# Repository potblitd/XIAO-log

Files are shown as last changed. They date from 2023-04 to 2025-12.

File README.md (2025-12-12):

<p align="center">
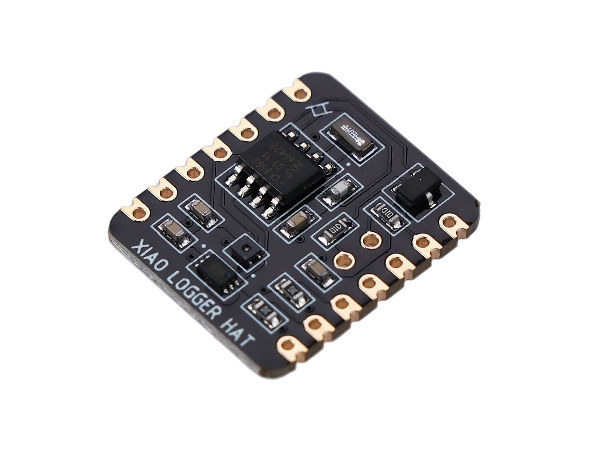
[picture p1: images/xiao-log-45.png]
  
  &nbsp;&nbsp;&nbsp;&nbsp;&nbsp;&nbsp;&nbsp;&nbsp;&nbsp;&nbsp;
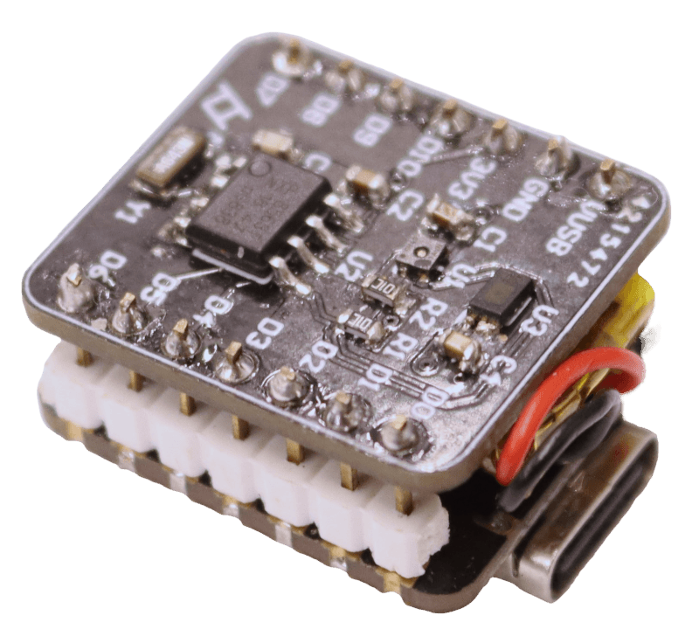
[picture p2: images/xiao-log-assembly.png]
  
</p>

An example _Arduino Zigbee_ code for the XIAO-log combined with a XIAO ESP32C6 micrcontroller can now be found [here](https://github.com/potblitd/XIAO-log/blob/main/zigbee/z-xiaohat.ino)

# XIAO log
The XIAO-LOG is a ‘hardware attached on top’ module for the XIAO Series microcontroller boards, providing temperature, humidity and ambient light measurements. The SHT40 and BH1750 sensors communicate through I2C, making it easy to program and get started. Their power supply is enabled by GPIO pin D10 to allow no-power sleep mode. Additionally, the onboard PCF8563 real-time clock can be used to keep precise timing and send a timed interrupt to the microcontroller. A voltage divider connected between the battery and the ADC output makes battery voltage monitoring possible. With its thumb-sized footprint and castellated header pins, this logger module perfectly fits on most of the XIAO boards and can accommodate more expansion boards. The module is a co-create collaboration with Seeed Studio and can be pruchased [here](https://www.seeedstudio.com/XIAO-LOG-p-6341.html).

## Description

The XIAO-LOG is a tiny environmental sensors module, specifically tailored for the XIAO microcontroller boards. It comprises two sensors : the SHT40 and the BH1750, measuring temperature, humidity, and ambient light. The chips use I2C communication on pin D4 and D5 to receive commands and send data to the XIAO microcontroller. On the same bus is also the PCF8563 real-time clock that provides precise timing and a programmable interrupt to wake up the XIAO board on pin D0 from deep sleep at exactly the right time. With these commonly used chips, the dev board can easily be programmed with existing libraries, both in micropython or on the arduino platform. 

For wireless battery-powered loggers, the resistor divider connecting the battery with ADC pin A3, is notably useful to monitor and keep track of the battery voltage level. To achieve the lowest power consumption, the sensors and the divider are powered through GPIO pin D10 while the always-on RTC chip only consumes about 250nA.

The dimensions of the XIAO-LOG board are the same as the XIAO boards, making it suitable for a sandwich configuration with the lithium-ion battery in between the two boards or for just stacking them. The castellated ‘post stamp’ headers on the board are friendly for breadboard setups and more HAT expansion layers.

## Specifications

| Item | Details |
| --- | --- |
| Size | 21mm x 17.75mm |
| Operating Temperature | -40°C to 85°C |
| Power Supply range | 2.4V ~ 3.6V |
| Current consumption | ~ 500uA |
| Idle current consumption | ~ 0.25uA |
| Communication Interface | I2C (D4/SDA and D5/SCL), ADC (D3/D3) |
| PCF8563 read time | TBA |
| SHT40 read time | ~ 2ms |
| BH1750 read time| ~ 120ms |
| Compatibility (all features) | XIAO ESP32C3, NRF54820, RP2350, MG24, ESP32C6 |
| Compatibility (no battery monitoring) | XIAO SAMD21, RP2040 | 

## Pinout Connections

## Programming

### Python
The easiest way to get micropython on the ESP32C3 chip is to download the firmware [here](https://micropython.org/download/), enter bootloader mode by holding the BOOT button down while pressing the RESET button, and then flash the chip with the bin file using [esptool](https://docs.espressif.com/projects/esptool/en/latest/esp32/) through the command prompt at the right COM port. With the [Thonny IDE](https://thonny.org/), the onboard files can easily be managed, and codes can be run directly without uploading them. 

This [basic code](code/xiaohat.py) implements all the features of the module.

Currently, the only way to connect the ESP32C3 board while in deep sleep for retrieving the log file, is to physically reset the board and click the restart backend button within the 10 seconds delay before the code continues and arrives back to deep sleep again. 

### Home Assistant 
The XIAO log devie can also be integrated into into Home Assistant thourgh ESPHome with this [example](code/esphome-xiaohat.yaml) code.

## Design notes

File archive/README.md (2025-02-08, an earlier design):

<p align="center">
  
</p>

# XIAO log

The lack of a simple and cost-effective device to measure temperature and humidity autonomously in remote, outdoor locations is astonishing. Specifically in ecological studies, to collect data, researchers often use the [Ibutton](https://www.ibuttonlink.com/collections/thermochron) logger that was released some 20 years ago and comes at a starting price of 36.70 USD. Needless to say, with today’s rise of CMOS, SoC, IoT and B2C, it’s about time to give those poor government-funded researchers an alternative and open-source solution for a simple temperature and humidity logging device. It should be noted that this post does not describe a buyable product but rather an easy setup with minimal components and cost.

## Materials

The XIAO log is composed of a microcontroller board, a battery and the temperature and humidity sensor probe. Although the [XIAO ESP32C3](https://www.seeedstudio.com/Seeed-XIAO-ESP32C3-p-5431.html) might seem a bit overkill for this application, it includes plenty of features that could be useful for future upgrades and variations. Also, its dirt [cheap](https://item.taobao.com/item.htm?spm=a230r.1.14.1.19487f1bpjLVY4&id=683550586572&ns=1&abbucket=17#detail) and trendy. For the sensor, a [waterproof probe](https://item.taobao.com/item.htm?spm=a230r.1.14.16.859f5271yamPh0&id=666936799925&ns=1&abbucket=17#detail) encasing the SHT40 chip (±0.2°C/±1.8%RH accuracy) should be suitable here. Lastly, the battery must be 3.7V lithium-ion to supply power and work with the dev board’s integrated battery charger. Its size can be chosen according to the housing dimensions. With [this waterproof box](https://detail.tmall.com/item.htm?id=681093549681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), the total cost of XIAO log is about 71.76 RMB or 10.45 USD.

<ins>Note</ins> : The XIAOs internal RTC is garbage. An external RTC should be used for reliable time keeping. See PCB shields [logRTC](#xiao-logrtc) or [log<sup>2</sup>](#log2).

<p align="center">
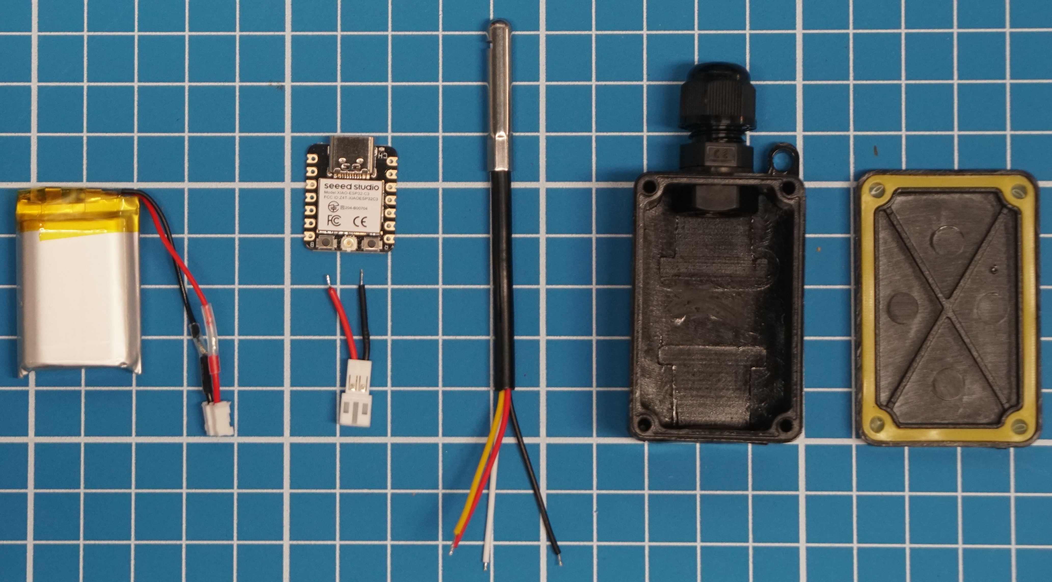
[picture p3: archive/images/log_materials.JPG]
  
</p>

## Assembly

Instead of soldering the battery directly onto the chip, a connector is fixed to facilitate removal and power OFF. The sensor uses I2C protocol which can be configured on pins D4 (SDA) and D5 (SCL). By connecting the VCC power supply for the sensor on a GPIO, such as D10, it can be powered only when needed and therefore reduce Xiao log's power consumption during his deep sleep period.

<p align="center">
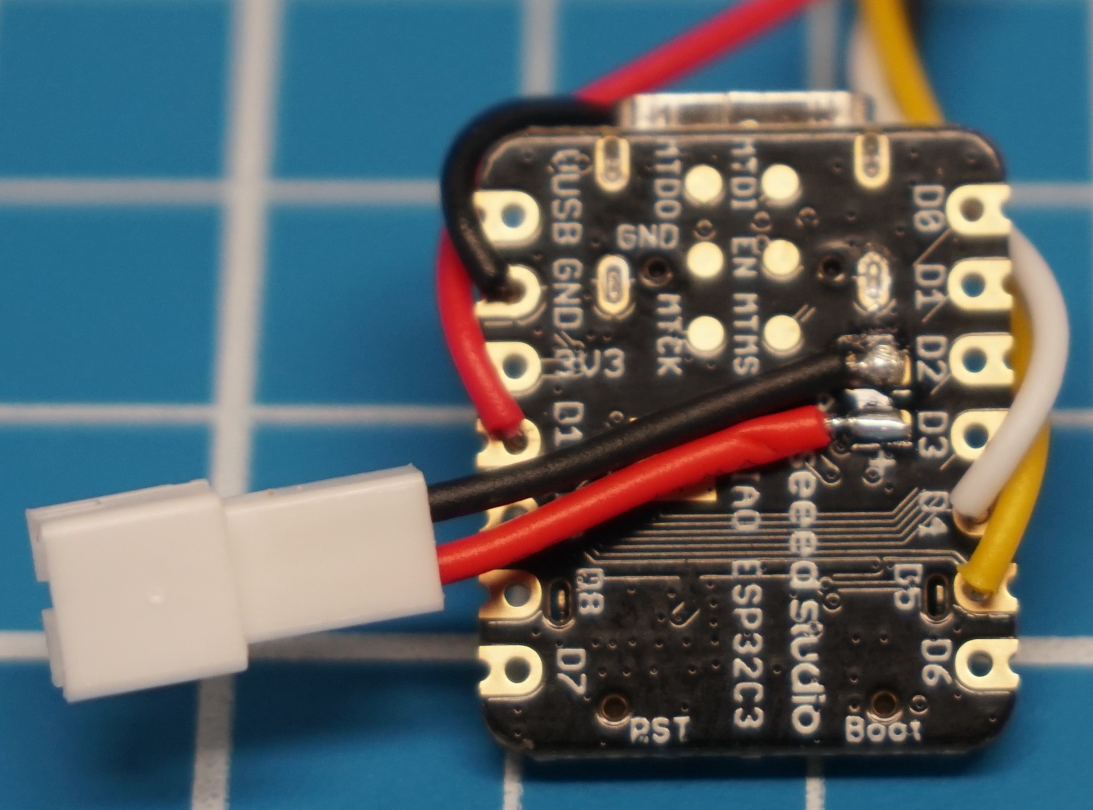
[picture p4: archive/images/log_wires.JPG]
  
  &nbsp;&nbsp;&nbsp;&nbsp;&nbsp;&nbsp;&nbsp;&nbsp;&nbsp;&nbsp;
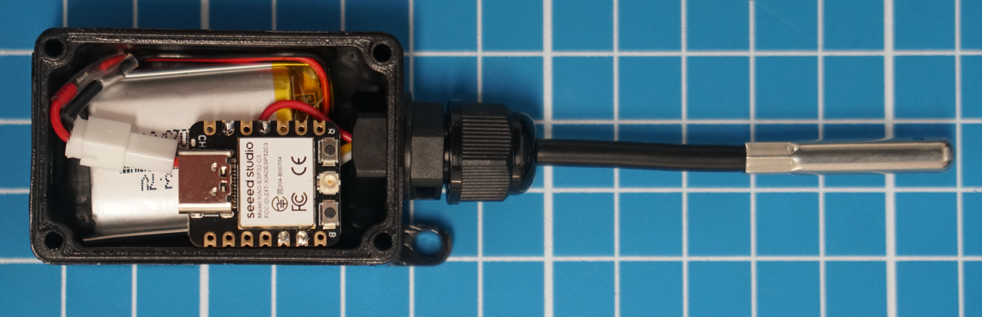
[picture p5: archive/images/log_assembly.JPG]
  
</p>

## Programming

The easiest way to get micropython on the ESP32C3 chip is to download the firmware [here](https://micropython.org/download/esp32c3-usb/), enter bootloader mode by holding the BOOT button down while pressing the RESET button, and then flash the chip with the bin file using [esptool](https://docs.espressif.com/projects/esptool/en/latest/esp32/) through the command prompt at the right COM port. With the [Thonny IDE](https://thonny.org/), the onboard files can easily be managed, and codes can be run directly without uploading them. The example code below is simple : it gets the RTC time, reads temperature and humidity from the sensor, writes all these values in a file and then calculates the time until the next measurement based on the logging period before going into deep sleep.

```ruby
# PARAMETERS
log_period = 60
 
# LIBRAIRIES
import os, time, machine

# DELAY ON RESET FOR IDE CONNECTION
if machine.reset_cause() == 1: time.sleep_ms(10000)
 
# DATE & TIME
now = time.localtime()
now_date = "-".join(map(str, now[0:3]))
now_time = ":".join(map(str, now[3:6]))
print("Date and time:", now_date, now_time)

# I2C INIT
i2c = machine.SoftI2C(sda=machine.Pin(6),scl=machine.Pin(7))

# TEMPERATURE & HUMIDITY
machine.Pin(10, machine.Pin.OUT).on()
time.sleep_ms(1)
i2c.writeto(0x44, bytes([0XFD]))
time.sleep_ms(10)
buf = i2c.readfrom(0x44, 6)
machine.Pin(10, machine.Pin.OUT).off()
temp = -45 + 175 * (buf[0]*256 + buf[1]) / 65535
humi = -6 + 125 * (buf[3]*256 + buf[4]) / 65535
print("Temperature: %0.2f C" % temp)
print("Humidity: %0.2f %%" % humi)
 
# VALUES LOG
if not "log.csv" in os.listdir():
    with open("log.csv", "a") as log:
        log.write("date,time,temp,hum\n")
with open("log.csv", "a") as log:
    log.write(now_date+","+now_time+","+str(temp)+","+str(humi)+"\n")
 
# DEEP SLEEP TIME
sleep_time = log_period - ((now[4]*60 + now[5]) % log_period)
print("Going to sleep for %0.2f minutes" % (sleep_time/60))
machine.deepsleep(sleep_time*1000)
# end
```

Currently, the only way to connect the ESP32C3 board while in deep sleep for retrieving the log file, is to physically reset the board and click the restart backend button within the 10 seconds delay before the code continues and arrives back to deep sleep again. 

## Performance

The current consumption during the measurements and logging is about 20mA and takes around 2 seconds. In deep sleep, XIAO log draws 42uA from his battery which is *nice* considering the RTC time is still running. So, with the 500mAh battery from this setup, XIAO log can theoretically run for 29 days with a 60 seconds logging cycle. The graph below shows his actual run with temperature, humidity and battery voltage measurement and file write every minute. After 35 days, the battery voltage dropped below 3.3V and the microcontroller stopped functioning which means the calculations above are reliable. With a log cycle of 10 minutes or 1 hour, XIAO log could therefore operate for 241 days or 392 days, respectively. 

<p align="center">
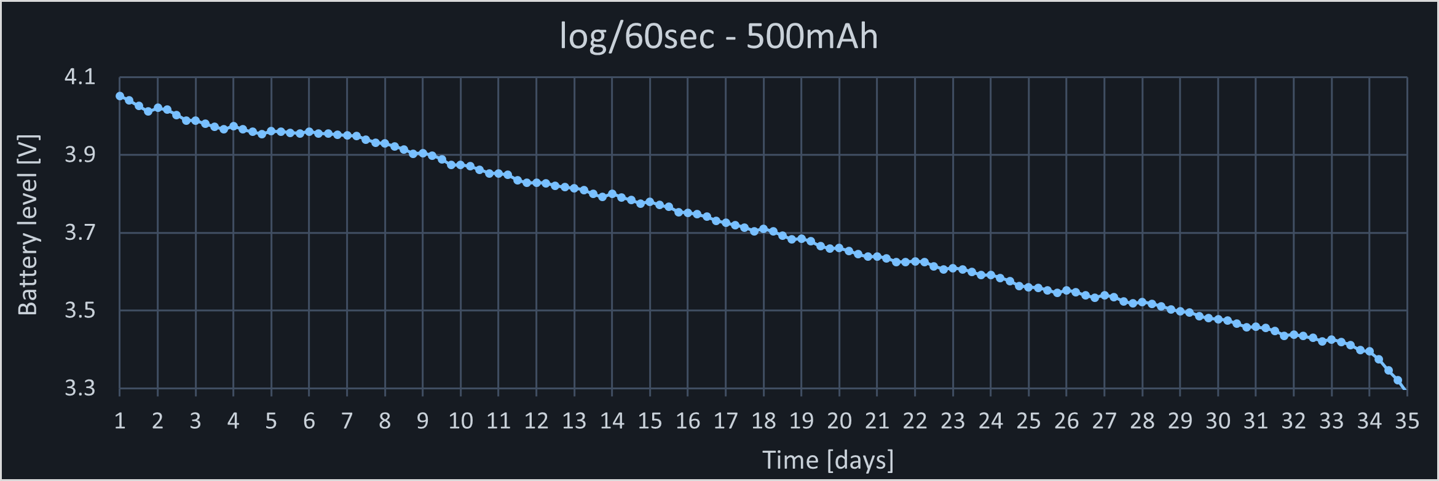
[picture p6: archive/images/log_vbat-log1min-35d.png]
  
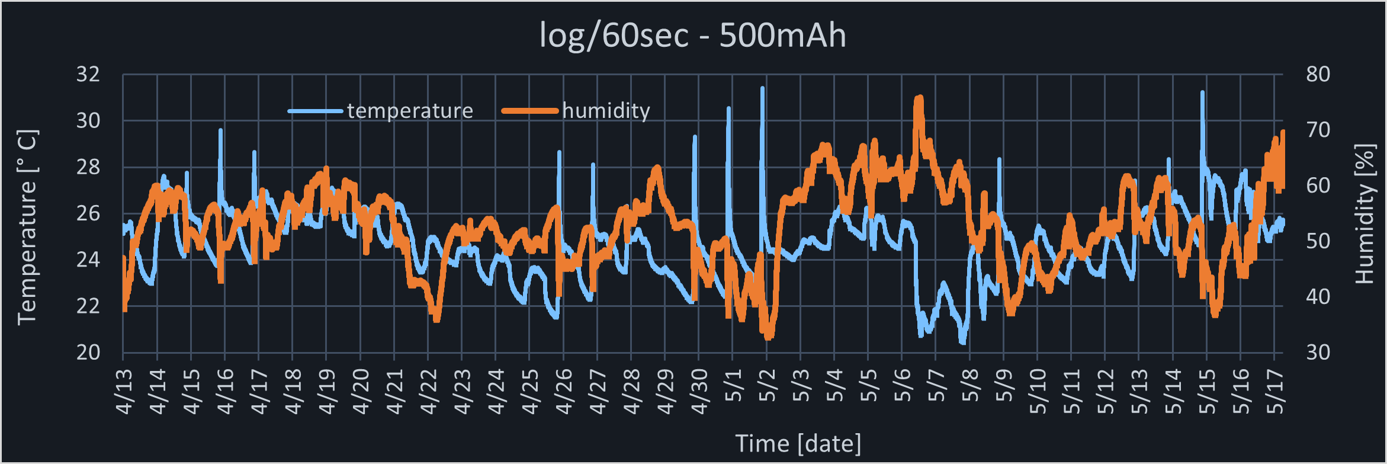
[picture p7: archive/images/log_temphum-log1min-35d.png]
  
</p>
It should also be noted that during this run, XIAO log didn't skip or mess up a single one of the total 49342 measurements and file logs. Good job XIAO log !

# [XIAO logRTC](logRTC)

Adding accurate time keeping and a battery voltage reading to the XIAO ESP32C3 with this weird shaped PCB. Here the PCF8563 RTC chip is powered continuously through the 3V3. The battery voltage divider is enabled through D10 and the halved voltage can be read on A3. Footprints and silkscreen are specifically designed to help for manual soldering.

<p align="center">
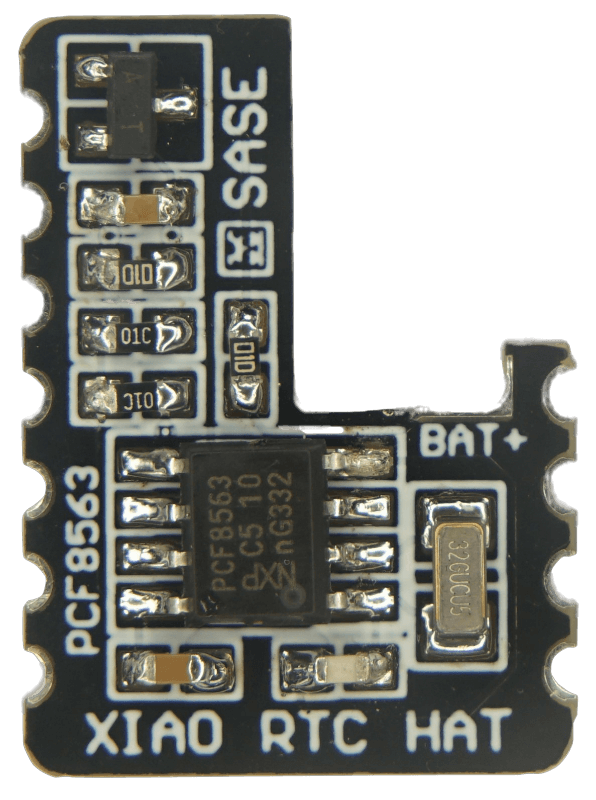
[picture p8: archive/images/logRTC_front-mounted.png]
  
  &nbsp;&nbsp;&nbsp;&nbsp;&nbsp;&nbsp;&nbsp;&nbsp;&nbsp;&nbsp;
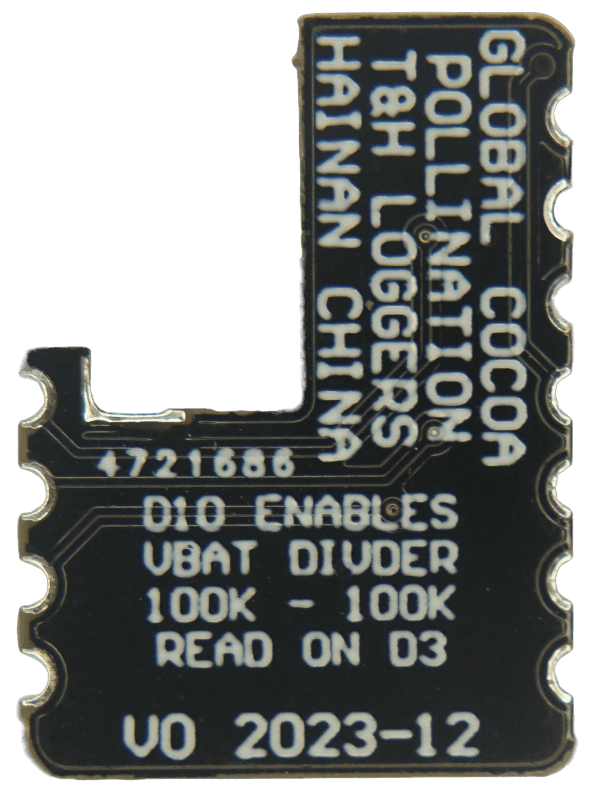
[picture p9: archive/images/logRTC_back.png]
  
</p>

## Assembly

After mounting the SMD components, the module is intended to be soldered directly onto the XIAO board (screw heat dissipation), connecting the BAT+ pins together while leaving space for a connector or wires. 

<p align="center">
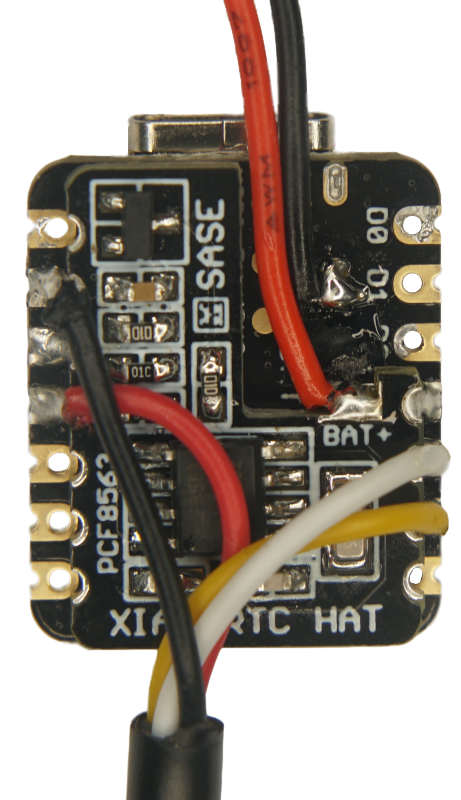
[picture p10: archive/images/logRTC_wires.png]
  
  &nbsp;&nbsp;&nbsp;&nbsp;&nbsp;&nbsp;&nbsp;&nbsp;&nbsp;&nbsp;
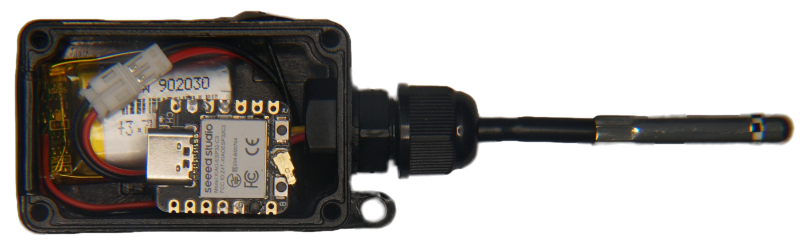
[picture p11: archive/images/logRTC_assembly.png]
  
</p>

## Code

[set_rtc.py](code/set_rtc.py) sets the time on PCF8563 form the local time on the PC.

The [xiaohat.py](code/xiaohat.py) code can be used for all variations in this repo. The *read_battery* parameter is used to enable battery voltage reading through D10 and A3. I2C comunication is initialized and, according to the adresses on the bus, values from the real-time clock (PCF8563), temperature & humidty sensor (SHT40) and ambient light sensor (BH1750) are retrieved. This data is then written into a file and send over WiFi to a cloud if *wifi_update* is enabled and its corresponding parameters are set up. Finally, the time until the next measurement is calculated based on the *log_period* time and deep sleep is activated.

Use the *test* variable to avoid the logger going to deep sleep and loosing connection when testing the code. Also, to access files when plugging the USB-C cable to a PC, resetting the board gives the user 10 seconds to connect to an IDE.

# [XIAO log<sup>2](log^2) <span id="log2"></span>

This design has 3 revisions. The latest one (V3) was adapted for the Seeed Studio Co-Create program.

Seeking compactness and all-in-one-ness, a logger hat hat was designed for the XIAO board. The design includes the previously used SHT40 temperature sensor, the popular BH1750 ambient light sensor and the PCF8563 RTC chip to correct the godawful internal clock. The RTC is powered by the 3V3 and the two sensor chips are powered through pin D10. Communication is done through I2C pins D4 (SDA) and D5 (SCL). V2 and V3 also features a battery voltage divider that is enabled through D10 and the halved voltage can be read on pin A3. This circuitry requires wiring the battery power to a through-hole pad on the hat. The PCB and components costs for this module sum up to 9.81 RMB (1.37 USD).

<p align="center">
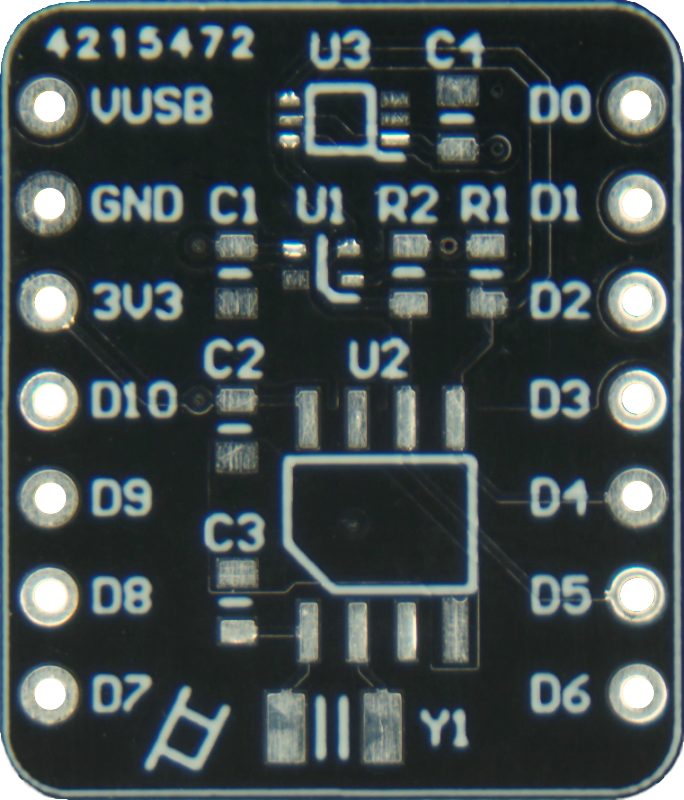
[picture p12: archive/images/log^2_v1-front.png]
  
  &nbsp;&nbsp;&nbsp;&nbsp;&nbsp;&nbsp;&nbsp;&nbsp;&nbsp;&nbsp;
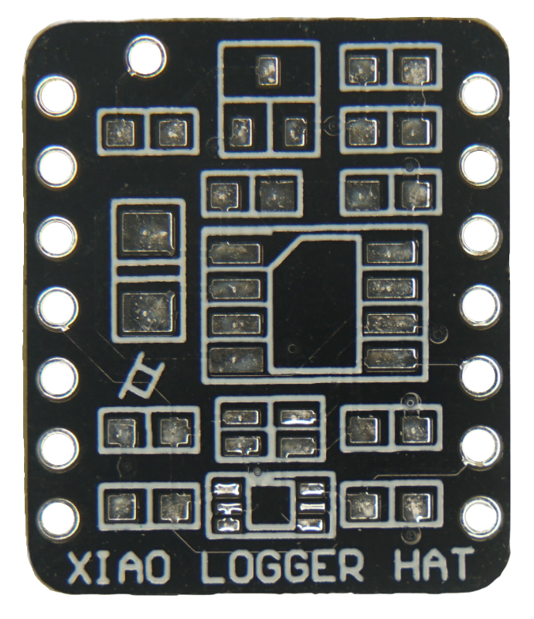
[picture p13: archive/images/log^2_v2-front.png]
  
  &nbsp;&nbsp;&nbsp;&nbsp;&nbsp;&nbsp;&nbsp;&nbsp;&nbsp;&nbsp;
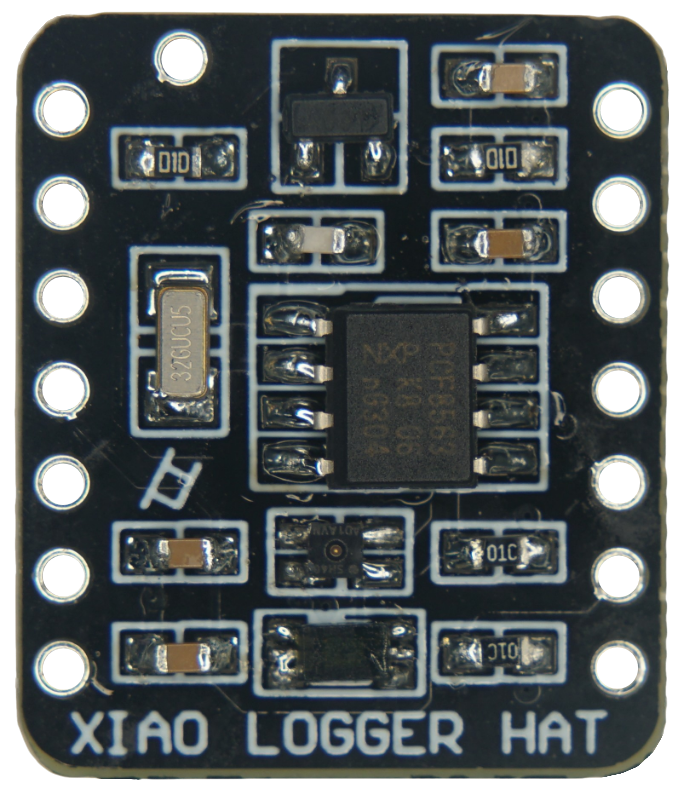
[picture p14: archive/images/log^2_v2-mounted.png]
  
</p>

## Assembly
SMD components are soldered on the shield first. V2 and V3 has adapted silkscreen and pads for easier manual soldering. The populated PCB is then soldered on the header pins of XIAO with an adequately-sized lithium battery sandwiched between the two boards. For V2 and V3, a wire must be added to get the battery voltage.

<p align="center">
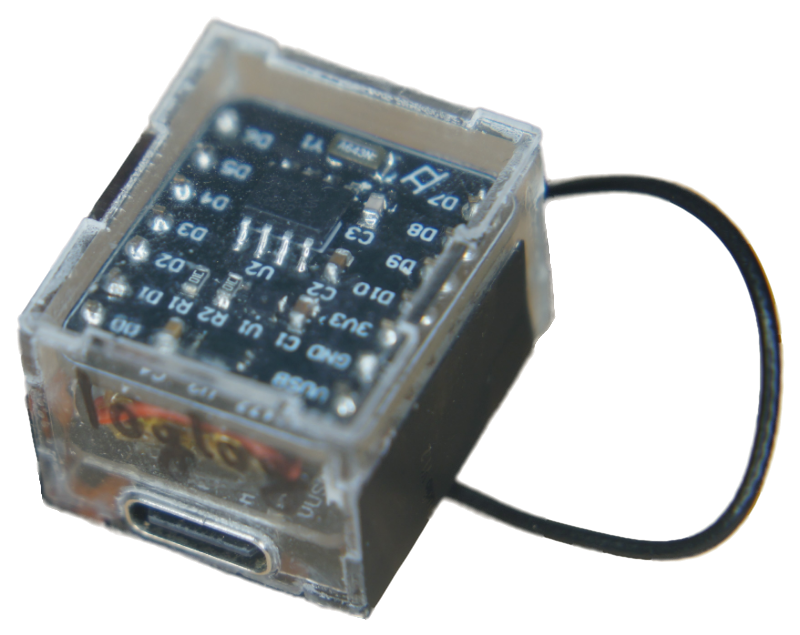
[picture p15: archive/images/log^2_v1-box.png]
  
  &nbsp;&nbsp;&nbsp;&nbsp;&nbsp;&nbsp;&nbsp;&nbsp;&nbsp;&nbsp;
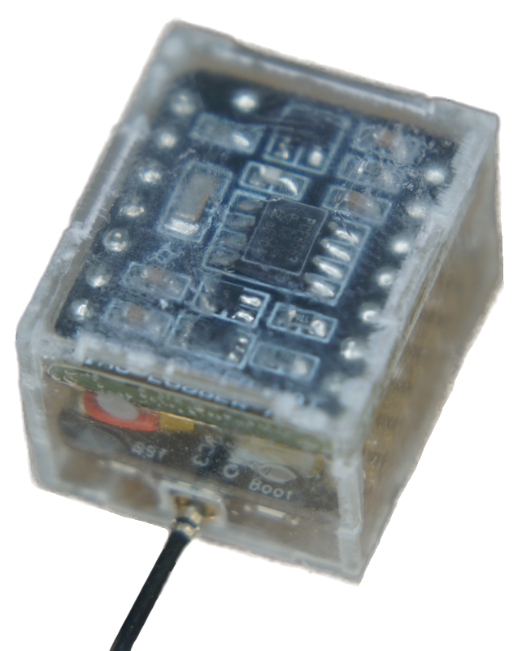
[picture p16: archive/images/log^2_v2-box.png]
  
  &nbsp;&nbsp;&nbsp;&nbsp;&nbsp;&nbsp;&nbsp;&nbsp;&nbsp;&nbsp;
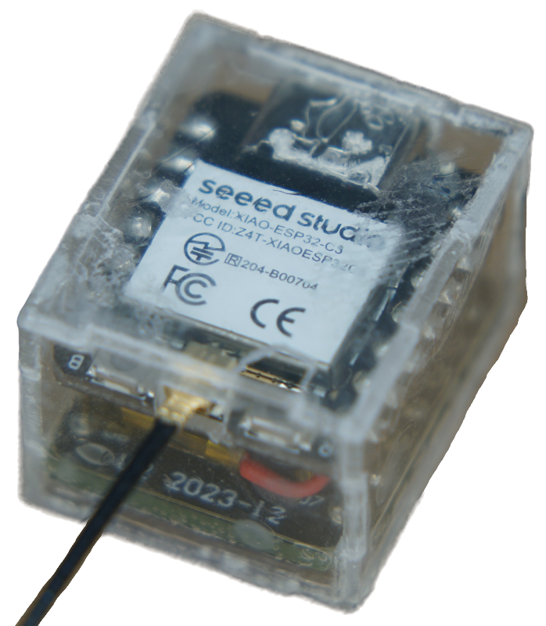
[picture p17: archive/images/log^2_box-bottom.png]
  
</p>

An acrylic cuboid was designed to tightly encase the entire system with holes for the USB-C connector, the U.FL antenna connector and access to the reset button. The complete assembly measures just 23.3 mm x 20 mm x 16.2 mm (without antenna) and the total cost is 46.65 RMB (6.52 USD).

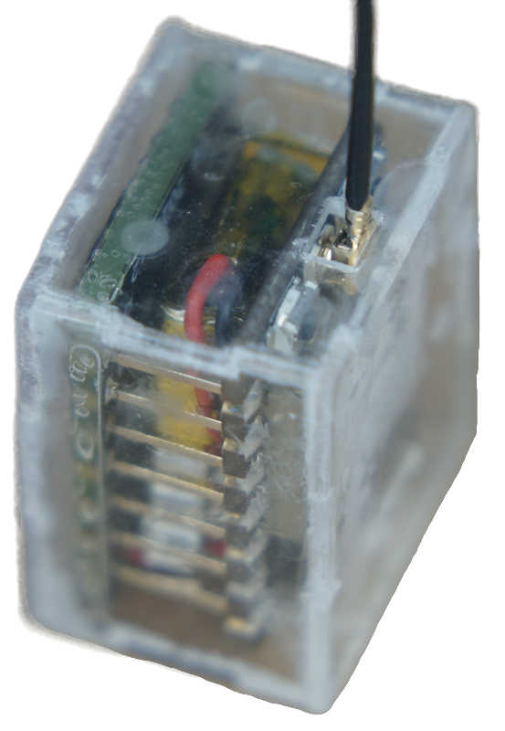
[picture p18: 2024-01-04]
images/log^2_box-side.png

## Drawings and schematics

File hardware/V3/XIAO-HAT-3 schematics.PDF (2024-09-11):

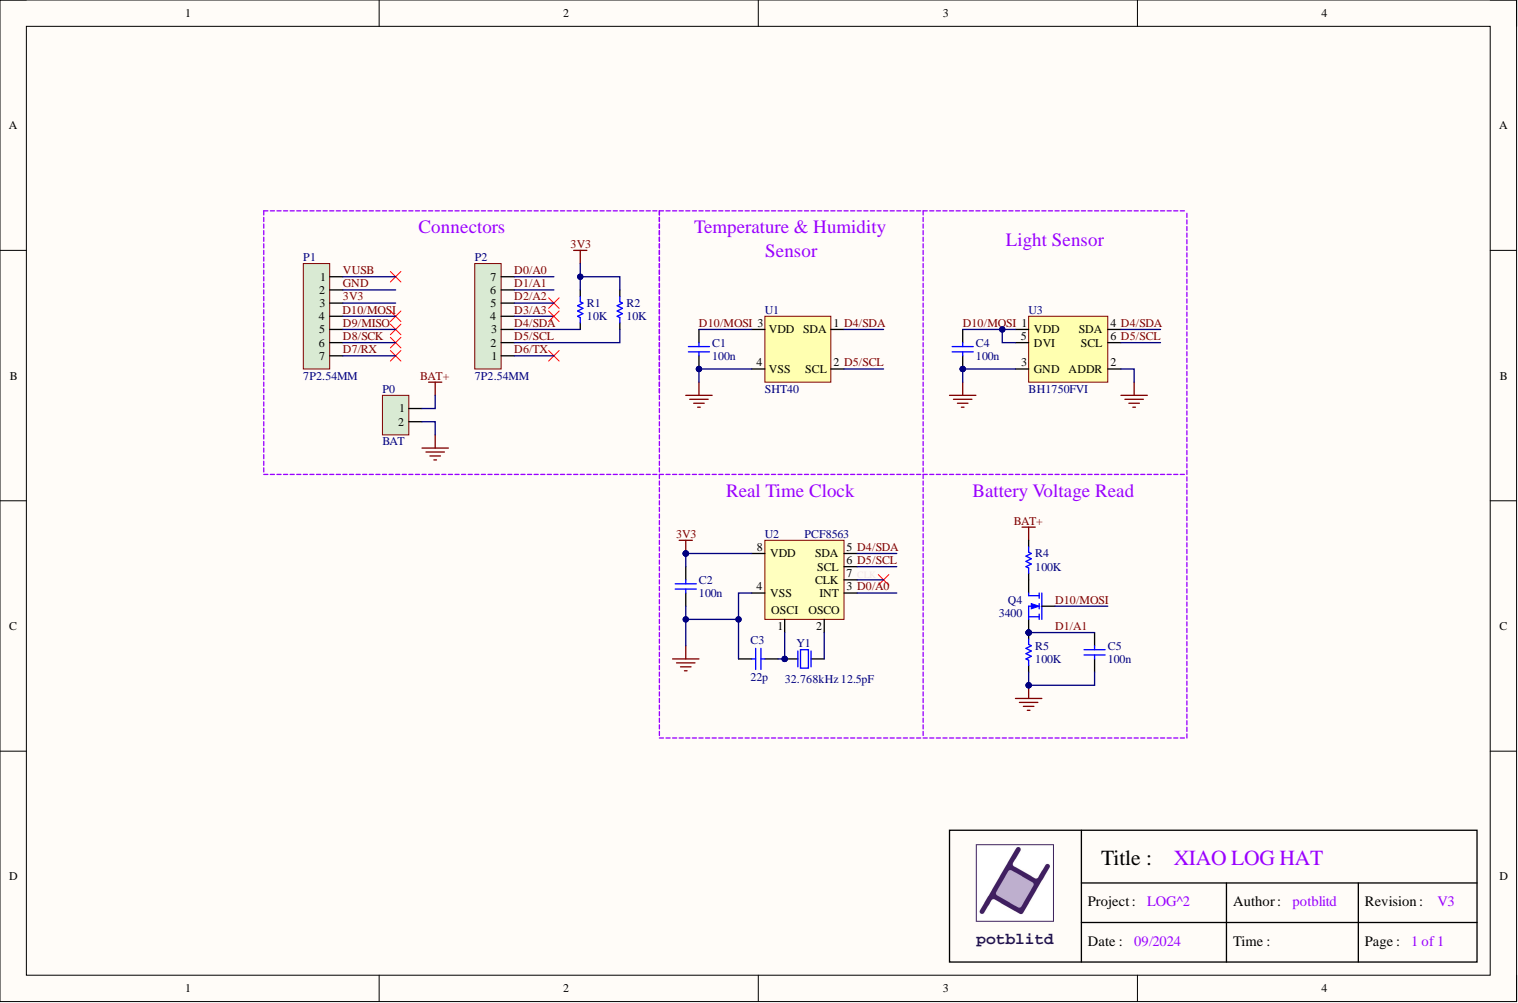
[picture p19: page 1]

potblitd | Title : XIAO LOG HA T

Proje ct : LO G ^ 2 | Auth or : p otb l i td | Re visio n : 1V 3

Date : 0 9 /2 0 2 4 | Time : | P a g e : 1 of

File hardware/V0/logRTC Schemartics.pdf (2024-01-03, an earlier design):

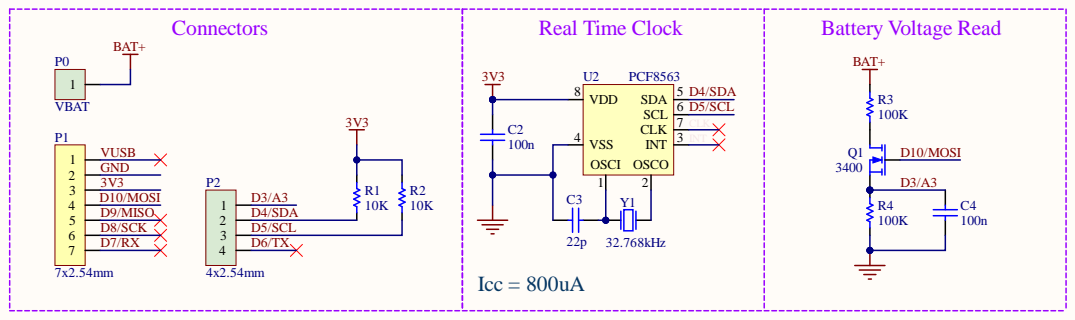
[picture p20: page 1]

mmVUSB GND 3V3 D10/MOSI D9/MISO D8/SCK D7/RX

potblitd | Title : lo g RTC

Proje ct : XIAO-lo g | Auth or : p otblitd | Re visio n : f 1V 1

Date : 1 2 /2 0 2 3 | Tim e : | P a g e : 1 o

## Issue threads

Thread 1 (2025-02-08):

logmain.py file is missing

matthiasbirkich, 2025-02-08:
Dear potblitd,

thank you very much for this really interesting project.
I ordered 5 Logger-HATs for the recording of Temperature, humidity and illuminance [lx].
What I am missing in the report is the logmain.py file for all parameters and maybe an example csv-file with data.
Are you so kind enough, to put that file into the code folder?
The links to some of the pictures are also broken…
Thank you. I wish you all the best, yours Matthias.

potblitd, 2025-02-08:
Hi Matthias, the main code is called xiaohat now. Its located [here](https://github.com/potblitd/XIAO-log/blob/main/code/xiaohat.py)
I updated the code and its name, and forgot to to change the link to it, sorry about that.

matthiasbirkich, 2025-02-08:
Hi, Marcel,

thank you very much for your quick answer. Does the unit of the sensor is
lux, not lum?

Best regards
Matthias

--
Matthias Birkicht
Georg-Seebeck-Straße 47
27570 Bremerhaven

work: +49 421 23 800 34

Marcel 芒芒 ***@***.***> schrieb am Sa. 8. Feb. 2025 um 09:27:

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

Closed 2025-02-09.

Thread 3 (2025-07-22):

code analysis and unit of BH1750 output

matthiasbirkich, 2025-07-22:
Dear Marcel,

I have seen one code snippet which is not a list but a dict:
if read_battery: readings.append({'field4':vbat}) -> if read_battery: readings['field4'] = vbat

I have recognized, that the ("Luminosity: %0.3f" % lum) should be  ("Illuminance: %0.3f lx" % Illum)

The Illuminance(400nm-700nm, peak 560nm) [lx] is the measurement of the BH1750 sensor according to the data sheet, when reading the ALS channel.

Suggestion:
To go for the whole range of the sensor (0.1 - 171000 lx ; Rohm data sheet), the reading could be adopted to bright or dark light like this example code:
———————————————————————————————————————
from machine import Pin, I2C
import time
import uos

# I2C Configuration — adjust pins if necessary
i2c = I2C(0, scl=Pin(6), sda=Pin(7), freq=400000)
BH1750_ADDR = 0x23

# BH1750 One-Time Measurement Modes
ONE_HIRES_MODE_1 = 0x20  # 1 lx / count
ONE_HIRES_MODE_2 = 0x21  # 0.5 lx / count
ONE_LORES_MODE   = 0x23  # 4 lx / count

CSV_FILENAME = "light_log.csv"

# Initialize CSV file if not already present
if CSV_FILENAME not in uos.listdir():
    with open(CSV_FILENAME, "w") as f:
        f.write("timestamp,mode,mtreg,raw,lux\n")

def set_mtreg(i2c, addr, mtreg):
    """Set MTReg (Measurement Time Register) value (21–254)."""
    if not (21 <= mtreg <= 254):
        raise ValueError("MTReg must be between 21 and 254.")
    high_byte = 0x40 | (mtreg >> 5)
    low_byte  = 0x60 | (mtreg & 0x1F)
    i2c.writeto(addr, bytes([high_byte]))
    i2c.writeto(addr, bytes([low_byte]))
    time.sleep_ms(10)

def read_raw_bh1750(i2c, addr, mode, mtreg):
    """Start a one-shot measurement and return raw 16-bit value."""
    set_mtreg(i2c, addr, mtreg)
    i2c.writeto(addr, bytes([mode]))
    base_delay = 180 if mode in (ONE_HIRES_MODE_1, ONE_HIRES_MODE_2) else 24
    time.sleep_ms(int(base_delay * mtreg / 69))
    data = i2c.readfrom(addr, 2)
    return int.from_bytes(data, 'big')

def calculate_lux(raw, mtreg, mode):
    """Calculate Lux using datasheet-correct formulas per mode."""
    scale = 1.2 * (mtreg / 69)

    if mode == ONE_HIRES_MODE_1:
        # 1 lx / count
        return raw / scale

    elif mode == ONE_HIRES_MODE_2:
        # 0.5 lx / count
        return raw / (scale * 2)

    elif mode == ONE_LORES_MODE:
        # 4 lx / count
        return raw / (scale * 4)

    else:
        raise ValueError("Unsupported measurement mode.")

def select_mode(lux_guess):
    """Decide which resolution mode to use based on estimated lux."""
    if lux_guess < 10:
        return ONE_HIRES_MODE_2
    elif lux_guess > 80000:
        return ONE_LORES_MODE
    else:
        return ONE_HIRES_MODE_1

def adaptive_bh1750_read(i2c, addr):
    """Measure lux with auto-adjusted MTReg and optimal resolution."""
    mtreg = 69
    mode = ONE_HIRES_MODE_1
    max_raw = 60000
    min_raw = 20000

    # Adaptive MTReg tuning
    for _ in range(4):
        raw = read_raw_bh1750(i2c, addr, mode, mtreg)
        lux = calculate_lux(raw, mtreg, mode)

        if raw > max_raw and mtreg > 21:
            mtreg = max(mtreg - 10, 21)
        elif raw < min_raw and mtreg < 254:
            mtreg = min(mtreg + 10, 254)
        else:
            break

    # Reevaluate mode based on estimated lux
    mode = select_mode(lux)
    raw = read_raw_bh1750(i2c, addr, mode, mtreg)
    lux = calculate_lux(raw, mtreg, mode)

    return lux, raw, mtreg, mode

def mode_label(mode):
    return {
        ONE_HIRES_MODE_1: "H1",
        ONE_HIRES_MODE_2: "H2",
        ONE_LORES_MODE: "L"
    }.get(mode, "?")

def timestamp_string():
    t = time.localtime()
    return "{:04d}-{:02d}-{:02d} {:02d}:{:02d}:{:02d}".format(*t[:6])

def log_to_flash():
    """Perform one measurement and store it in CSV format."""
    lux, raw, mtreg, mode = adaptive_bh1750_read(i2c, BH1750_ADDR)
    entry = f"{timestamp_string()},{mode_label(mode)},{mtreg},{raw},{lux:.2f}"
    print(entry)
    with open(CSV_FILENAME, "a") as f:
        f.write(entry + "\n")

# Logging loop: adjust interval as needed (currently 60 minutes)
while True:
    log_to_flash()
    time.sleep(60 * 60)  # 60 minutes

————————————————————————————————————————-
Reference: https://www.mouser.com/catalog/specsheets/Rohm_11162017_ROHMS34826-1.pdf
The expanded calculation for illuminance in one shot high resolution mode 1 is: lux = raw / (1.2 * (mtreg/69))
The expanded calculation for illuminance in one shot high resolution mode 2 is: lux = raw / (1.2 * (mtreg/69)*2)
The expanded calculation for illuminance in one shot low resolution mode is: lux = raw / (1.2 * (mtreg/69)*4)
Than you will have the same specification like a commercial HOBO-Logger and bright sunlight can be measured as well as moon light.
I hope my documentation is fine and you could integrate that suggestions into your code.
Thank you for your interest and cooperation.

Best regards
Matthias

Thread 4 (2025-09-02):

Battery charging

Minecodes, 2025-09-02:
As far as I can see it's only documented that you could use this board to monitor the battery. But does it support charging too?

Closed 2025-09-09.

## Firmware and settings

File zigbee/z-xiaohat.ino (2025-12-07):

#ifndef ZIGBEE_MODE_ED
#error "Zigbee end device mode is not selected in Tools->Zigbee mode"
#endif

// import necessary libraries
#include <Wire.h>
#include <Arduino.h>
#include "Zigbee.h"
#include <SensirionI2cSht4x.h>
#include <BH1750.h>

// zigbee configs from https://docs.espressif.com/projects/arduino-esp32/en/latest/libraries.html#zigbee-apis
#define TEMP_SENSOR_ENDPOINT_NUMBER 10
// using analog device to transfer the lux value
#define ANALOG_DEVICE_ENDPOINT_NUMBER 1
// Conversion factor for micro seconds to seconds
#define uS_TO_S_FACTOR 1000000ULL
// Sleep for 5 minutes
#define TIME_TO_SLEEP 300
// Timeout for response from coordinator in ms
#define REPORT_TIMEOUT 2000 
// Set to 0 to use local callback specified directly for the endpoint.
#define USE_GLOBAL_ON_RESPONSE_CALLBACK 1  
uint8_t dataToSend = 2;
bool resend = false; 

ZigbeeTempSensor zbTempSensor = ZigbeeTempSensor(TEMP_SENSOR_ENDPOINT_NUMBER);
ZigbeeAnalog zbAnalogLux = ZigbeeAnalog(ANALOG_DEVICE_ENDPOINT_NUMBER);

// define pin connections with XIAO board
uint8_t led = LED_BUILTIN;
uint8_t button = BOOT_PIN;
const int ADC_pin = A1;

// setup temp & hum sensor
SensirionI2cSht4x sht40;
static char errorMessage[64];
static int16_t error;
// setup light sensor
BH1750 bh1750;

/************************ Callbacks *****************************/
#if USE_GLOBAL_ON_RESPONSE_CALLBACK
void onGlobalResponse(zb_cmd_type_t command, esp_zb_zcl_status_t status, uint8_t endpoint, uint16_t cluster) {
  Serial.printf("Global response command: %d, status: %s, endpoint: %d, cluster: 0x%04x\r\n", command, esp_zb_zcl_status_to_name(status), endpoint, cluster);
  if ((command == ZB_CMD_REPORT_ATTRIBUTE) && (endpoint == TEMP_SENSOR_ENDPOINT_NUMBER)) {
    switch (status) {
      case ESP_ZB_ZCL_STATUS_SUCCESS: dataToSend--; break;
      case ESP_ZB_ZCL_STATUS_FAIL:    resend = true; break;
      default:                        break;  // add more statuses like ESP_ZB_ZCL_STATUS_INVALID_VALUE, ESP_ZB_ZCL_STATUS_TIMEOUT etc.
    }
  }
}
#else
void onResponse(zb_cmd_type_t command, esp_zb_zcl_status_t status) {
  Serial.printf("Response command: %d, status: %s\r\n", command, esp_zb_zcl_status_to_name(status));
  if (command == ZB_CMD_REPORT_ATTRIBUTE) {
    switch (status) {
      case ESP_ZB_ZCL_STATUS_SUCCESS: dataToSend--; break;
      case ESP_ZB_ZCL_STATUS_FAIL:    resend = true; break;
      default:                        break;  // add more statuses like ESP_ZB_ZCL_STATUS_INVALID_VALUE, ESP_ZB_ZCL_STATUS_TIMEOUT etc.
    }
  }
}
#endif

/********************* Arduino functions **************************/
void setup() {
  
  Serial.begin(115200);
  Serial.println("Zigbee device start");

  // Configure builtin LED and turn it OFF (HIGH)
  pinMode(led, OUTPUT);
  digitalWrite(led, HIGH);
  // Init button for factory reset
  pinMode(button, INPUT_PULLUP);
  // setup ADC battery voltage pin
  pinMode(ADC_pin, INPUT);

  // initialize I2C communication
  Wire.begin();

  // init SHT40 sensor
  sht40.begin(Wire, SHT40_I2C_ADDR_44);
  sht40.softReset();
  delay(10);
  uint32_t serialNumber = 0;
  error = sht40.serialNumber(serialNumber);
  if (error != 0) {
      Serial.print("Error trying to execute serialNumber(): ");
      errorToString(error, errorMessage, sizeof errorMessage);
      Serial.println(errorMessage);
      return;
  }
  Serial.print("serialNumber: ");
  Serial.print(serialNumber);
  Serial.println();

  // get sht40 measurements
  float temp = 0.0;
  float humi = 0.0;

  delay(20);
  error = sht40.measureLowestPrecision(temp, humi);
  if (error != 0) {
      Serial.print("Error trying to execute measureLowestPrecision(): ");
      errorToString(error, errorMessage, sizeof errorMessage);
      Serial.println(errorMessage);
      return;
  }
  Serial.print("Temperature: ");
  Serial.print(temp);
  Serial.print("\t");
  Serial.print("Humidity: ");
  Serial.print(humi);
  Serial.println();

  // initialize BH1750 sensor
  bh1750.begin();

  // Get luminosity from bh1750 sensor
  uint16_t lux = bh1750.readLightLevel();
  // print results
  Serial.print("Light: ");
  Serial.print(lux);
  Serial.println();

  // Get battery voltage
  uint32_t Vbat = 0;
  for(int i = 0; i < 10; i++) {
    Vbat = Vbat + analogReadMilliVolts(ADC_pin);
    delay(20);
  }
  float Vbatf = 2 * Vbat / 10 / 1000.0;
  float Vbatp = (Vbatf - 3) * (100) / (1.2);
  if (Vbatp < 0) { Vbatp = 0;
  } else if (Vbatp > 100) { Vbatp = 100;}
  // print results
  Serial.print("Battery voltage: ");
  Serial.print(Vbatf, 3);
  Serial.print(" V");
  Serial.println("\t");
  Serial.print("Battery percentage: ");
  Serial.print(Vbatp, 1);
  Serial.println(" %");

  // Configure the wake up source and set to wake up every 30 minutes
  esp_sleep_enable_timer_wakeup(TIME_TO_SLEEP * uS_TO_S_FACTOR);

  //set tempsensor zigbee settings
  zbTempSensor.setManufacturerAndModel("Z-XIAO", "HAT");
  zbTempSensor.setMinMaxValue(-20, 80);
  zbTempSensor.setTolerance(1);
  zbTempSensor.addHumiditySensor(0, 100, 1);
  // Set up analog input for lux value
  zbAnalogLux.addAnalogInput();
  zbAnalogLux.setAnalogInputApplication(ESP_ZB_ZCL_AI_COUNT_UNITLESS_OTHER);
  zbAnalogLux.setAnalogInputDescription("Illuminance");
  zbAnalogLux.setAnalogInputResolution(1);

#if USE_GLOBAL_ON_RESPONSE_CALLBACK
  // Global callback for all endpoints with more params to determine the endpoint and cluster in the callback function.
  Zigbee.onGlobalDefaultResponse(onGlobalResponse);
#else
  // Callback specified for endpoint
  zbTempSensor.onDefaultResponse(onResponse);
#endif

  //Add endpoints to Zigbee Core
  Zigbee.addEndpoint(&zbTempSensor);
  Zigbee.addEndpoint(&zbAnalogLux);
  // Create a default Zigbee configuration for End Device
  esp_zb_cfg_t zigbeeConfig = ZIGBEE_DEFAULT_ED_CONFIG();
  zigbeeConfig.nwk_cfg.zed_cfg.keep_alive = 10000;
  // Set timeout for Zigbee Begin to 10s (default is 30s)
  Zigbee.setTimeout(10000);  
  Serial.println("Starting Zigbee...");

  // When all EPs are registered, start Zigbee. By default acts as ZIGBEE_END_DEVICE
  if (!Zigbee.begin(&zigbeeConfig, false)) {
    Serial.println("Zigbee failed to start!");
    Serial.println("Rebooting...");
    ESP.restart();
  } else {
    Serial.println("Zigbee started successfully!");
  }

  Serial.println("Connecting to network");
  while (!Zigbee.connected()) {
    Serial.print(".");
    delay(300);
  }
  Serial.println();
  Serial.println("Successfully connected to Zigbee network");
  // Delay approx 1s (may be adjusted) to allow establishing proper connection with coordinator, needed for sleepy devices
  delay(1000);

  // Update temperature and humidity values in Temperature sensor EP
  zbTempSensor.setTemperature(temp);
  zbTempSensor.setHumidity(humi);
  //zbTempSensor.setBatteryPercentage(Vbatp);
  //zbTempSensor.setBatteryVoltage(Vbatf*10);
  zbAnalogLux.setAnalogInput(lux);
  // Report values
  zbTempSensor.report();
  delay(100);
  //zbTempSensor.reportBatteryPercentage();
  zbAnalogLux.reportAnalogInput();
  
  unsigned long startTime = millis();
  const unsigned long timeout = REPORT_TIMEOUT;

  Serial.printf("Waiting for data report to be confirmed \r\n");
  // Wait until data was successfully sent
  int tries = 0;
  const int maxTries = 5;
  while (dataToSend != 0 && tries < maxTries) {
    if (resend) {
      Serial.println("Resending data on failure!");
      resend = false;
      dataToSend = 2;
      zbTempSensor.report();  // report again
      zbAnalogLux.reportAnalogInput();
    }
    if (millis() - startTime >= timeout) {
      Serial.println("\nReport timeout! Report Again");
      dataToSend = 2;
      zbTempSensor.report();  // report again
      zbAnalogLux.reportAnalogInput();
      startTime = millis();
      tries++;
    }
    Serial.printf(".");
    delay(100);  // 50ms delay to avoid busy-waiting
  }

  // Put device to deep sleep
  Serial.printf("Going to sleep for %d seconds\r\n", TIME_TO_SLEEP);
  esp_deep_sleep_start();
}

void loop() {
  // nothing here
}

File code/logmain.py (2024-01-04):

# PARAMETERS
log_period = 60*30
test = True
read_battery = True
wifi_update = False
ssid = ''
password = ''
url = ''

# LIBRAIRIES
import os, time, machine, sys
if wifi_update: import network, urequests

# CONNECTION ON RESET
if machine.reset_cause() == 1: time.sleep_ms(10000)

# SENSORS POWER ON
machine.Pin(10, machine.Pin.OUT).on()

# BATTERY VOLTAGE
if read_battery:
    adc = machine.ADC(machine.Pin(5), atten = machine.ADC.ATTN_11DB)
    time.sleep_ms(100)
    vbat = round(adc.read_uv()/1000/1000*2, 3)
    if test : print("Battery voltage: %0.3f V" % vbat)

# I2C INIT
i2c = machine.SoftI2C(sda = machine.Pin(6), scl = machine.Pin(7))
i2c_devices = i2c.scan()
if test : print('I2C adresses currently on the line :',i2c_devices)

# PCF8563 - DATE & TIME
if 81 in i2c_devices:
    rtc_masks = [0x7F,0x7F,0x3F,0x3F,0x07,0x1F,0xFF]
    rtc = [None]*7
    for i in range(0,7):
        bcd = i2c.readfrom_mem(0x51, i+2, 1)[0] & rtc_masks[i]
        rtc[i] = (((bcd & 0xf0) >> 4) * 10 + (bcd & 0x0f))
        
    rtc_date = str(rtc[6]+2000)+"-"+str(rtc[5])+"-"+str(rtc[3])
    rtc_time = str(rtc[2])+":"+str(rtc[1])+":"+str(rtc[0])
    if test : print("Date and time:", rtc_date, rtc_time)
else:
    rtc_date = 'NA'
    rtc_time = 'NA'

# SHT40 - TEMPERATURE & HUMIDITY
if 68 in i2c_devices:
    i2c.writeto(0x44, bytes([0xFD])) # set hi-res mode
    time.sleep_ms(10)
    buf = i2c.readfrom(0x44, 6)
    temp = round(-45 + 175 * (buf[0]<<8 | buf[1]) / 65535, 3)
    humi = round(-6 + 125 * (buf[3]<<8 | buf[4]) / 65535, 3)
    if test :
        print("Temperature: %0.3f C" % temp)
        print("Humidity: %0.3f %%" % humi)
else:
    temp = 'NA'
    humi = 'NA'    

# BH1750 - LUMINOSITY
if 35 in i2c_devices:
    time.sleep_ms(1)
    i2c.writeto(0x23, bytes([0x01])) # power on
    i2c.writeto(0x23, bytes([0x07])) # reset
    i2c.writeto(0x23, bytes([0x20])) # set once hi-res mode
    time.sleep_ms(180)
    data = i2c.readfrom(0x23, 2)
    lum = round((data[0]<<8 | data[1]) / 1.2, 3)
    if test : print("Luminosity: %0.3f" % lum)
else: lum = 'NA'
    
# SENSORS POWER OFF
machine.Pin(10, machine.Pin.OUT).off()

# WIFI UPDATE
if wifi_update:
    uploaded = False
    connected = False
    sta_if = network.WLAN(network.STA_IF)
    sta_if.active(True)
    sta_if.connect(ssid, password)
    # try to connect
    for i in range(100):  
        if sta_if.isconnected():
            connected = True
            break                
        else: time.sleep_ms(100)
    # try to send data
    if connected:
        print("Connected to WiFi")
        readings = {'field1':temp, 'field2':humi, 'field3':lum}
        if read_battery: readings.append('field4':vbat)
        try:
            request = urequests.post(url, json = readings, headers = {'Content-Type': 'application/json'})  
            request.close()
            print("Data sent")
            uploaded = True
        except Exception as e: print("Data transfer failed")
        sta_if.disconnect()
    else: print("Connection failed")
    # disconnect
    sta_if.active(False)
    
# VALUES LOG
if not "log.csv" in os.listdir():
    with open("log.csv", "a") as log:
        log.write("date,time,temp,hum,lum")
        if read_battery: log.write(",vbat")
        if wifi_update: log.write(",connected,uploaded")
        log.write("\n")
        
with open("log.csv", "a") as log:
    log.write(rtc_date+","+rtc_time+","+str(temp)+","+str(humi)+","+str(lum))
    if read_battery: log.write(","+str(vbat))
    if wifi_update: log.write(","+str(connected)+","+str(uploaded))
    log.write("\n")
    
# DEEP SLEEP TIME
if not test:
    sleep_time = log_period - ((rtc[1]*60 + rtc[0]) % log_period)
    if sleep_time < 30: sleep_time = sleep_time + log_period
    machine.deepsleep(sleep_time*1000)
# end

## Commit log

2023-12-19 add XIAO logger shield
    [XIAO-HAT.PcbDoc, XIAO-HAT.SchDoc]
2024-01-03 rearrange everything
    [XIAO-HAT.PcbDoc, XIAO-HAT.SchDoc, XIAO-log^2-2.PcbDoc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]
2024-07-10 add log^3 folder and files
    [XIAO-HAT-3.PcbDoc, XIAO-HAT-3.SchDoc]
2024-07-10 include V2 in log^2
    [XIAO-HAT-3.PcbDoc, XIAO-HAT-3.SchDoc]
2024-07-11 update schematic size
    [XIAO-HAT-3.PcbDoc, XIAO-HAT-3.SchDoc]
2024-08-05 update assembly layer
    [XIAO-HAT-3.PcbDoc]
2024-08-07 update pin header hole sizes
    [XIAO-HAT-3.PcbDoc]
2024-08-10 update XIAO-HAT V3
    [XIAO-HAT-3.PcbDoc]
2024-09-11 update XIAO-HAT design with new footprints for fabrication
    [XIAO-HAT-3.PcbDoc, XIAO-HAT-3.SchDoc]
2025-12-02 rearrange folders
    [XIAO-HAT-3.PcbDoc, XIAO-HAT-3.SchDoc, XIAO-log^2-2.PcbDoc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]
2026-10-22 Fix V3 battery sensing pin in README and MicroPython example
2026-10-22 correct xiaohat.py ADC pin
2026-10-22 add priority to ensure smooth power-on in esphome-xiaohat.yaml
